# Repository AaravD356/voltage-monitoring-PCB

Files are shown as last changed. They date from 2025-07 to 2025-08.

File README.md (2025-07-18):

### UMD Mars Rover Electrical Team

### Voltage Monitoring PCB
This project involves a custom PCB designed to monitor the voltage of a multi-cell battery pack and transmit the readings over a CAN bus. The core of the system is an STM32 microcontroller, which reads the voltage of each cell through voltage divider circuits. The measured values are then transmitted via a SN65HVD230 CAN transceiver to a Jetson Nano, which acts as the receiver and processor.

### System Overview
The PCB includes six voltage divider circuits, one for each battery cell, to scale down the cell voltages to a level readable by the STM32's ADC inputs. The STM32 continuously reads these voltages and formats the data into a CAN message. The SN65HVD230 transceiver handles communication over the CAN bus, ensuring reliable data transfer to the Jetson Nano or any compatible receiver.

### CAN Communication
Each CAN message contains the measured voltages, formatted as an array of 16-bit unsigned integers representing millivolts. A static CAN ID is used to identify messages from the monitoring board. This ID can be customized in the STM32 firmware if needed.

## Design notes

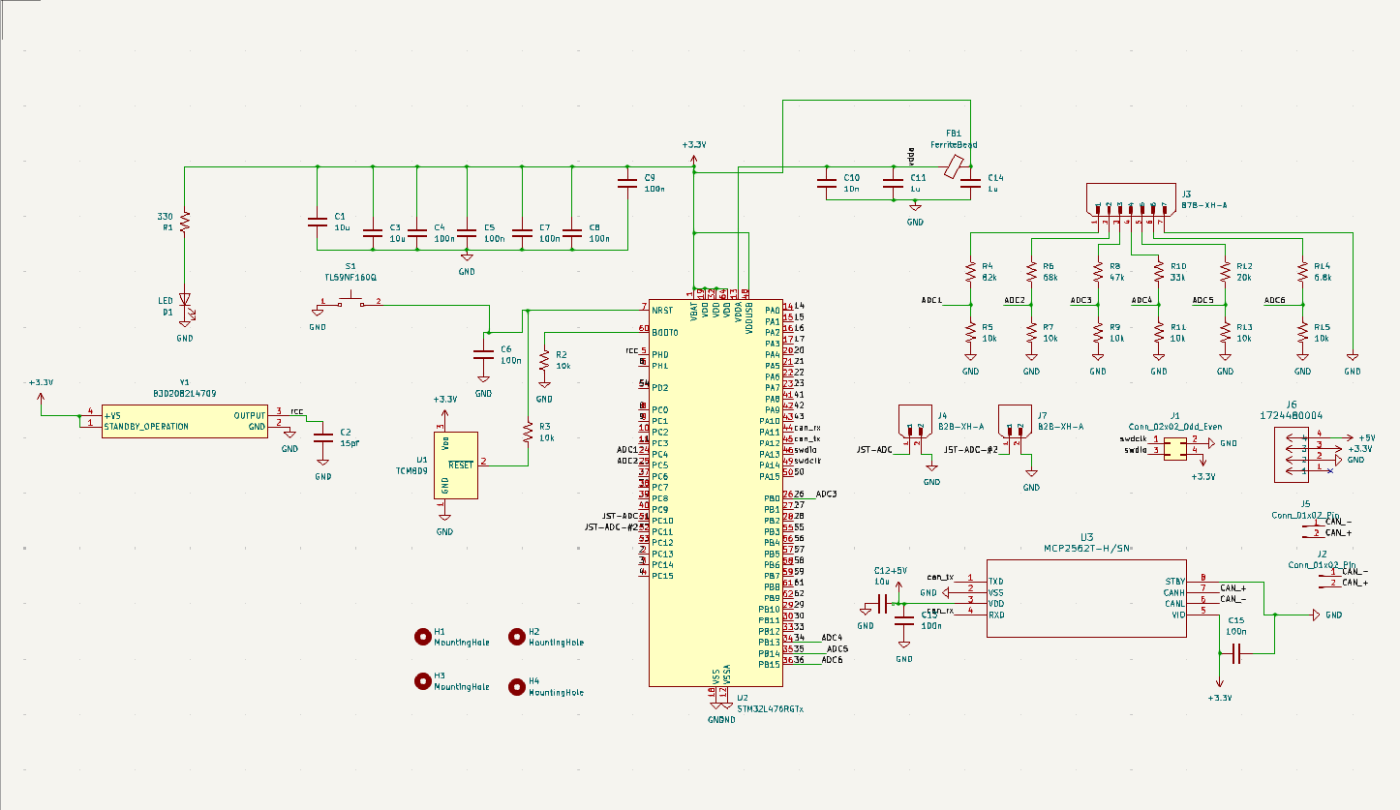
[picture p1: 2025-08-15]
Schematic.png

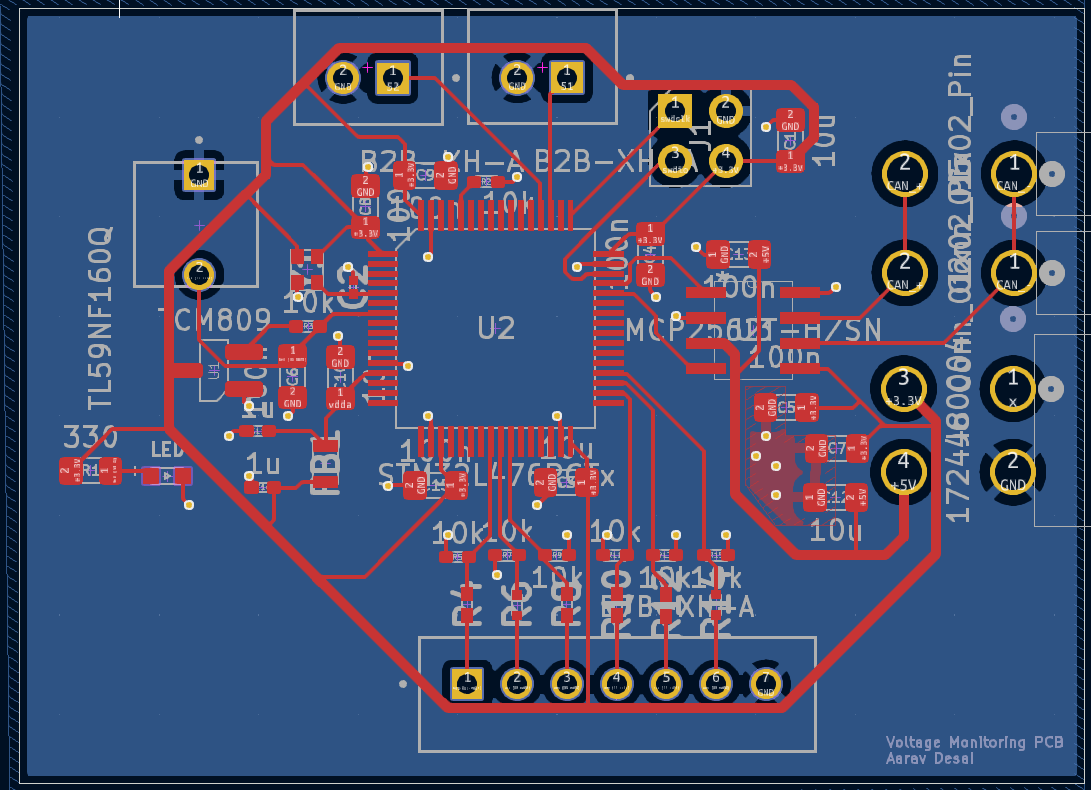
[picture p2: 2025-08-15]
Layout.png

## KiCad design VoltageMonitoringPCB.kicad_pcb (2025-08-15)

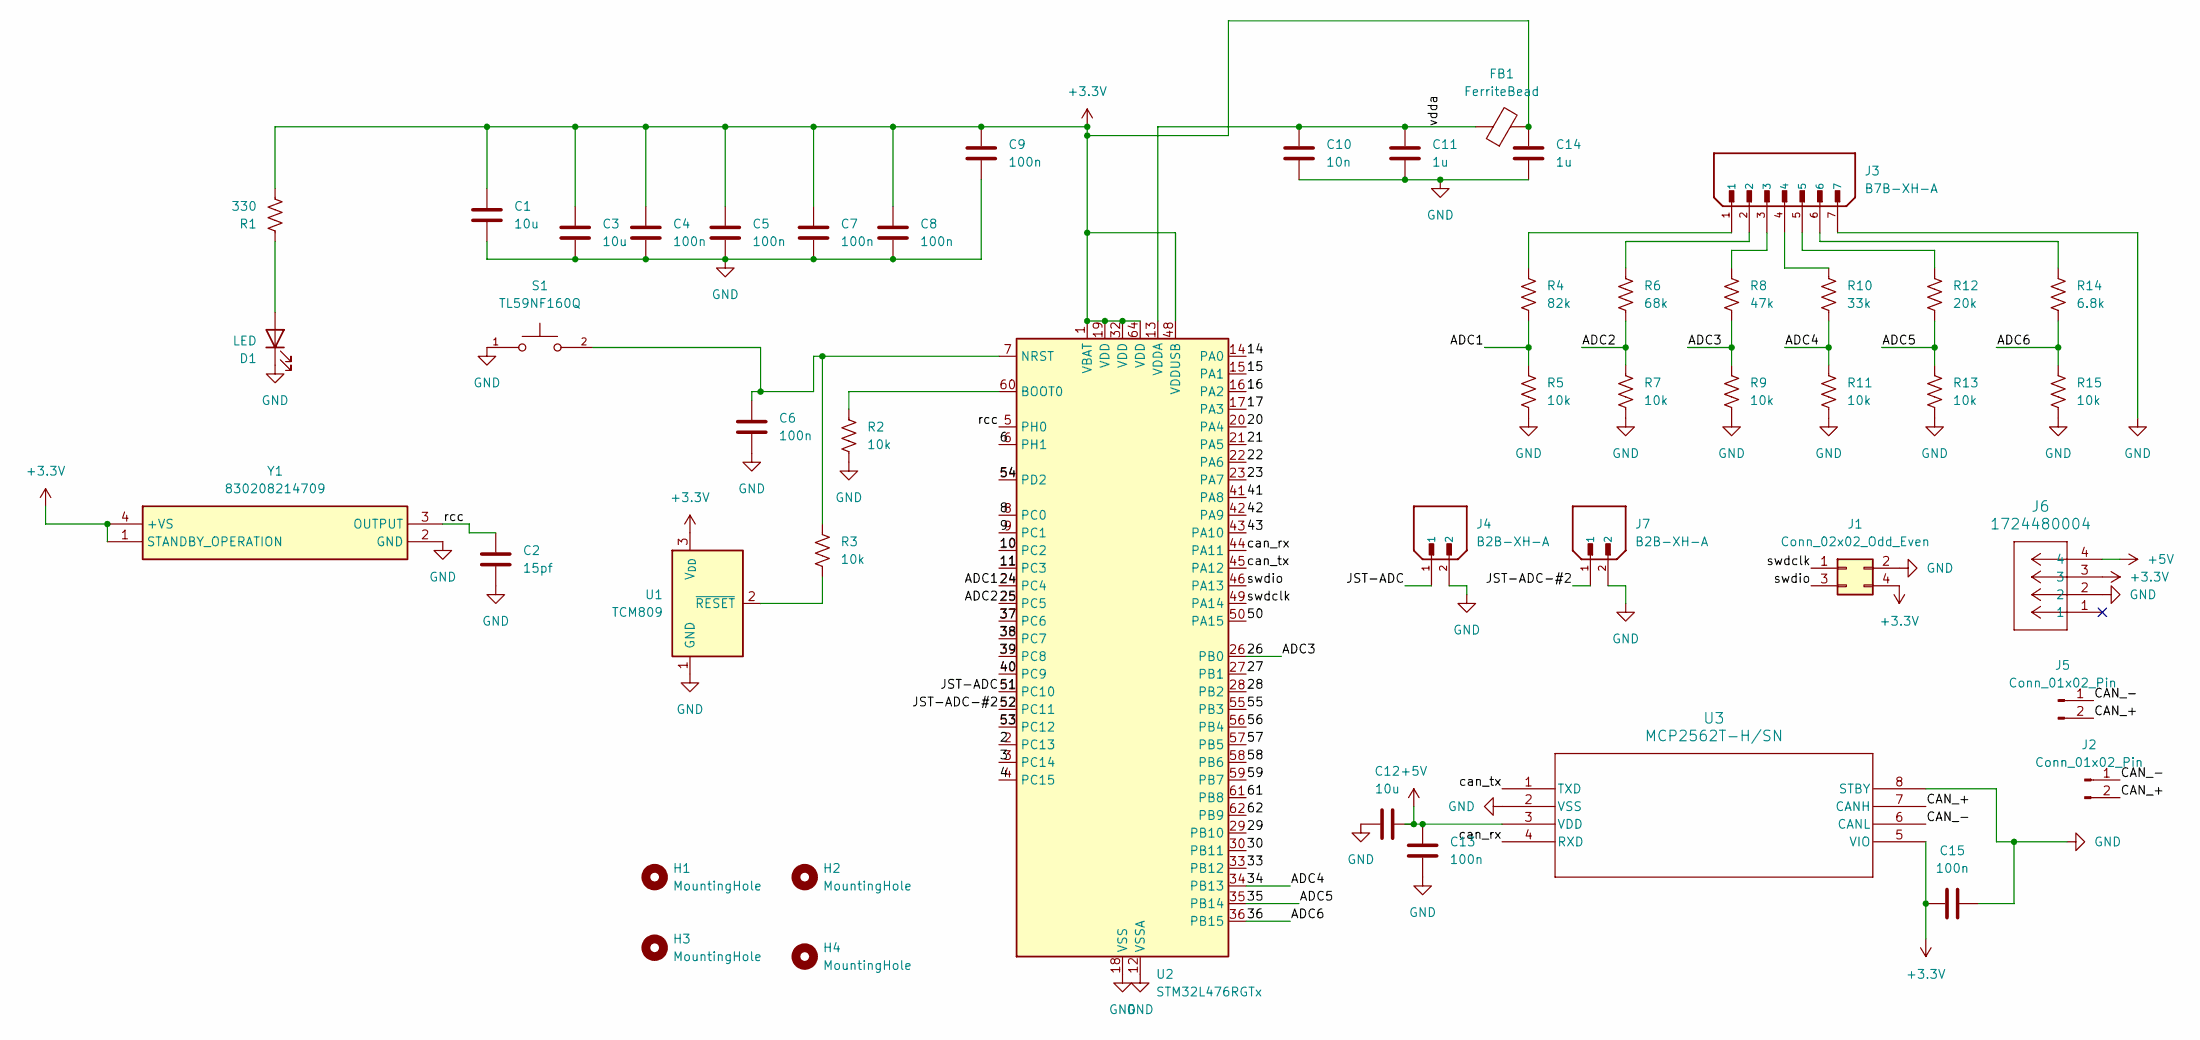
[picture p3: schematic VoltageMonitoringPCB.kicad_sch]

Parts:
C1, C3, C12: 10u; C_0805_2012Metric_Pad1.18x1.45mm_HandSolder
C2: 15pf; 15pf_cap
C4, C5, C6, C7, C8, C9, C13, C15: 100n; C_0805_2012Metric_Pad1.18x1.45mm_HandSolder
C10: 10n; C_0805_2012Metric_Pad1.18x1.45mm_HandSolder
C11, C14: 1u; C_0402_1005Metric_Pad0.74x0.62mm_HandSolder
D1: LED; small_led
FB1: FerriteBead; ferrite_bead02BH1J
H1, H2, H3, H4: MountingHole
J1: Conn_02x02_Odd_Even; PinHeader_2x02_P2.54mm_Vertical
J2, J5: Conn_01x02_Pin; can_molex_header
J3: B7B-XH-A; 7-PinJST-ad; PARTREV 7/4/21
J4, J7: B2B-XH-A; 2-PinJST-ad; PARTREV N/A
J6: 1724480004; power_header
R1: 330; R_0805_2012Metric_Pad1.20x1.40mm_HandSolder
R2, R3, R5, R7, R9, R11, R13, R15: 10k; R_0402_1005Metric_Pad0.72x0.64mm_HandSolder
R4: 82k; 82kOhmRes-ad
R6: 68k; 68kOhmRes-ad
R8: 47k; 47kOhmRes-ad
R10: 33k; 33kOhmRes-ad
R12: 20k; 20kOhmRes-ad
R14: 6.8k; 6.8kOhmRes-ad
S1: TL59NF160Q; reset_button; PARTREV G
U1: TCM809; SOT-23_Handsoldering
U2: STM32L476RGTx; LQFP-64_10x10mm_P0.5mm
U3: MCP2562T-H/SN; can_transceiver
Y1: 830208214709; oscillator; Mouser Part Number 710-830208214709

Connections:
+3.3V: C1.1, C3.1, C4.1, C5.1, C7.1, C8.1, C9.1, C14.1, C15.1, FB1.2, J1.4, J6.3, R1.2, U1.3 (V_{DD}), U2.1 (VBAT), U2.19 (VDD), U2.32 (VDD), U2.48 (VDDUSB), U2.64 (VDD), U3.5 (VIO), Y1.1 (STANDBY_OPERATION), Y1.4 (+VS)
+5V: C12.2, C13.2, J6.4, U3.3 (VDD)
/2: U2.2 (PC13)
/3: U2.3 (PC14)
/4: U2.4 (PC15)
/6: U2.6 (PH1)
/8: U2.8 (PC0)
/9: U2.9 (PC1)
/10: U2.10 (PC2)
/11: U2.11 (PC3)
/14: U2.14 (PA0)
/15: U2.15 (PA1)
/16: U2.16 (PA2)
/17: U2.17 (PA3)
/20: U2.20 (PA4)
/21: U2.21 (PA5)
/22: U2.22 (PA6)
/23: U2.23 (PA7)
/24: R4.2, R5.1, U2.24 (PC4)
/25: R6.2, R7.1, U2.25 (PC5)
/26: R8.2, R9.1, U2.26 (PB0)
/27: U2.27 (PB1)
/28: U2.28 (PB2)
/29: U2.29 (PB10)
/30: U2.30 (PB11)
/33: U2.33 (PB12)
/34: R10.2, R11.1, U2.34 (PB13)
/35: R12.2, R13.1, U2.35 (PB14)
/36: R14.2, R15.1, U2.36 (PB15)
/37: U2.37 (PC6)
/38: U2.38 (PC7)
/39: U2.39 (PC8)
/40: U2.40 (PC9)
/41: U2.41 (PA8)
/42: U2.42 (PA9)
/43: U2.43 (PA10)
/50: U2.50 (PA15)
/51: J4.1, U2.51 (PC10)
/52: J7.1, U2.52 (PC11)
/53: U2.53 (PC12)
/54: U2.54 (PD2)
/55: U2.55 (PB3)
/56: U2.56 (PB4)
/57: U2.57 (PB5)
/58: U2.58 (PB6)
/59: U2.59 (PB7)
/61: U2.61 (PB8)
/62: U2.62 (PB9)
/CAN_+: J2.2, J5.2, U3.7 (CANH)
/CAN_-: J2.1, J5.1, U3.6 (CANL)
/can_rx: U2.44 (PA11), U3.4 (RXD)
/can_tx: U2.45 (PA12), U3.1 (TXD)
/rcc: C2.1, U2.5 (PH0), Y1.3 (OUTPUT)
/swdclk: J1.1, U2.49 (PA14)
/swdio: J1.3, U2.46 (PA13)
/vdda: C10.1, C11.1, FB1.1, U2.13 (VDDA)
GND: C1.2, C2.2, C3.2, C4.2, C5.2, C6.2, C7.2, C8.2, C9.2, C10.2, C11.2, C12.1, C13.1, C14.2, C15.2, D1.1 (K), J1.2, J3.7, J4.2, J6.2, J7.2, R2.2, R5.2, R7.2, R9.2, R11.2, R13.2, R15.2, S1.1, U1.1 (GND), U2.12 (VSSA), U2.18 (VSS), U2.31 (VSS), U2.47 (VSS), U2.63 (VSS), U3.2 (VSS), U3.8 (STBY), Y1.2 (GND)
unnamed: D1.2 (A), R1.1
unnamed: J3.1, R4.1
unnamed: J3.2, R6.1
unnamed: J3.3, R8.1
unnamed: J3.4, R10.1
unnamed: J3.5, R12.1
unnamed: J3.6, R14.1
unnamed: R3.2, U1.2 (~RESET)
unnamed: R2.1, U2.60 (BOOT0)
unnamed: C6.1, R3.1, S1.2, U2.7 (NRST)

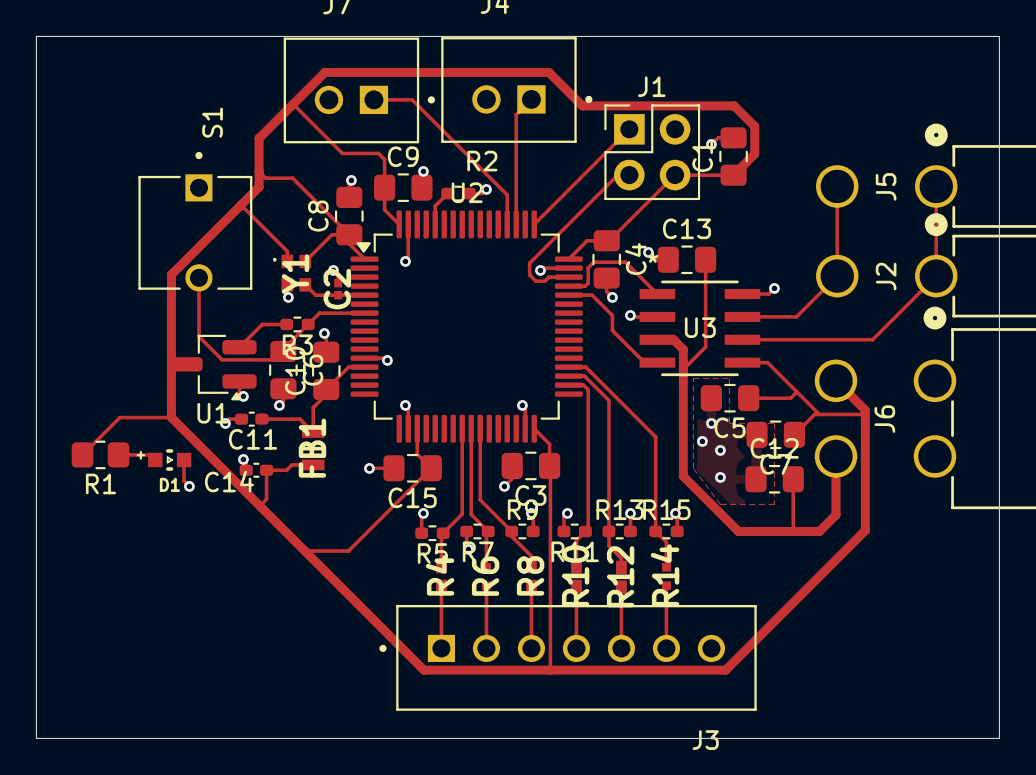
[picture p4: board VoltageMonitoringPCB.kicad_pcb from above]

Board: 2 copper layers, 53.5 x 39.0 mm, 44 parts (0 on the bottom side), 29 nets.

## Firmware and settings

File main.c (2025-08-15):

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

#include "main.h"
#include <string.h>
#include <stdbool.h>

/* =================== CONFIG =================== */
// Firmware version
#define FW_MAJOR        1
#define FW_MINOR        0
#define FW_PATCH        0
#define FW_VERSION_U32  ((FW_MAJOR<<24)|(FW_MINOR<<16)|(FW_PATCH))

// ADC config
#define NUM_ADC_CH      6
#define ADC_SAMPLES     16
#define VREF_MV         3300
#define ADC_FS_COUNTS   4095.0f

// ADC scan order indices
enum {
  CH_ADC1 = 0, // PC4
  CH_ADC2,     // PC5
  CH_ADC3,     // PB0
  CH_ADC4,     // PB13
  CH_ADC5,     // PB14
  CH_ADC6      // PB15
};

// Divider gains (Rtop+Rbot)/Rbot
static const float k_divider_gain[NUM_ADC_CH] = {
  9.2f,   // ADC1: 82k/10k
  7.8f,   // ADC2: 68k/10k
  5.7f,   // ADC3: 47k/10k
  4.3f,   // ADC4: 33k/10k
  3.0f,   // ADC5: 20k/10k
  1.68f   // ADC6: 6.8k/10k
};

// Fault thresholds
#define UV_TRIP_MV        3000
#define UV_WARN_MV        3200
#define OV_WARN_MV        4200
#define OV_TRIP_MV        4250
#define IMBALANCE_WARN_MV 100
#define FAULT_DEBOUNCE_MS 500

// MCP2562 STBY pin
#define CAN_STBY_GPIO_Port     GPIOB
#define CAN_STBY_Pin           GPIO_PIN_2

// Relay JSTs (initialized, unused)
#define RELAY1_GPIO_Port       GPIOC
#define RELAY1_Pin             GPIO_PIN_10
#define RELAY2_GPIO_Port       GPIOC
#define RELAY2_Pin             GPIO_PIN_11

// CAN IDs
#define CAN_ID_HEARTBEAT   0x300
#define CAN_ID_VOLTAGES_1  0x301
#define CAN_ID_VOLTAGES_2  0x302
#define CAN_ID_FAULTS      0x303

/* =================== PRIVATE VARS =================== */
ADC_HandleTypeDef hadc1;
DMA_HandleTypeDef hdma_adc1;
CAN_HandleTypeDef hcan;
TIM_HandleTypeDef htim2;

static volatile uint16_t adc_dma_buf[NUM_ADC_CH * ADC_SAMPLES];
static volatile uint16_t meas_mV[NUM_ADC_CH];

static volatile uint32_t uptime_ms = 0;
static uint32_t last_hb_ms = 0;
static uint32_t last_tx_ms = 0;
static uint32_t status_bits = 0;

/* =================== PROTOTYPES =================== */
void SystemClock_Config(void);
static void MX_GPIO_Init(void);
static void MX_DMA_Init(void);
static void MX_ADC1_Init(void);
static void MX_CAN_Init(void);
static void MX_TIM2_Init(void);

static void start_adc_dma(void);
static void process_adc_window(void);
static void evaluate_faults(void);
static void can_send_std(uint16_t id, const uint8_t *data, uint8_t len);
static void tx_heartbeat(void);
static void tx_voltages(void);
static void tx_faults(void);

/* =================== MAIN =================== */
int main(void)
{
  HAL_Init();
  SystemClock_Config();

  MX_GPIO_Init();
  MX_DMA_Init();
  MX_ADC1_Init();
  MX_CAN_Init();
  MX_TIM2_Init();

  // Enable CAN transceiver
  HAL_GPIO_WritePin(CAN_STBY_GPIO_Port, CAN_STBY_Pin, GPIO_PIN_RESET);

  HAL_CAN_Start(&hcan);
  HAL_CAN_ActivateNotification(&hcan, CAN_IT_TX_MAILBOX_EMPTY);
  HAL_TIM_Base_Start_IT(&htim2);

  start_adc_dma();

  while (1)
  {
    uint32_t now = uptime_ms;

    if (now - last_hb_ms >= 500) {
      tx_heartbeat();
      last_hb_ms = now;
    }
    if (now - last_tx_ms >= 100) {
      tx_voltages();
      tx_faults();
      last_tx_ms = now;
    }
    HAL_Delay(5);
  }
}

/* =================== CALLBACKS =================== */
void HAL_TIM_PeriodElapsedCallback(TIM_HandleTypeDef *htim)
{
  if (htim == &htim2) uptime_ms++;
}

void HAL_ADC_ConvCpltCallback(ADC_HandleTypeDef *hadc)
{
  if (hadc == &hadc1) {
    process_adc_window();
    evaluate_faults();
  }
}

/* =================== FUNCTIONS =================== */
static void start_adc_dma(void)
{
  HAL_ADC_Start_DMA(&hadc1, (uint32_t*)adc_dma_buf, NUM_ADC_CH * ADC_SAMPLES);
}

static void process_adc_window(void)
{
  for (int ch = 0; ch < NUM_ADC_CH; ch++) {
    uint32_t acc = 0;
    for (int s = 0; s < ADC_SAMPLES; s++)
      acc += adc_dma_buf[ch + s*NUM_ADC_CH];
    float avg_counts = (float)acc / ADC_SAMPLES;
    float mv_adc = (avg_counts * VREF_MV) / ADC_FS_COUNTS;
    float mv_node = mv_adc * k_divider_gain[ch];
    if (mv_node < 0) mv_node = 0;
    if (mv_node > 65535) mv_node = 65535;
    meas_mV[ch] = (uint16_t)mv_node;
  }
}

static void evaluate_faults(void)
{
  uint32_t faults = 0;
  uint16_t vmin = 0xFFFF, vmax = 0;

  for (int ch = 0; ch < NUM_ADC_CH; ch++) {
    uint16_t v = meas_mV[ch];
    if (v <= UV_TRIP_MV) faults |= (1u << ch);
    if (v >= OV_TRIP_MV) faults |= (1u << (8 + ch));
    vmin = (v < vmin) ? v : vmin;
    vmax = (v > vmax) ? v : vmax;
  }
  if ((uint16_t)(vmax - vmin) >= IMBALANCE_WARN_MV)
    faults |= (1u << 16);

  static uint32_t first_fault_ms = 0;
  if (faults) {
    if (!first_fault_ms) first_fault_ms = uptime_ms;
    if (uptime_ms - first_fault_ms >= FAULT_DEBOUNCE_MS)
      status_bits = faults;
  } else {
    first_fault_ms = 0;
    status_bits = 0;
  }
}

static void can_send_std(uint16_t id, const uint8_t *data, uint8_t len)
{
  CAN_TxHeaderTypeDef tx = {0};
  uint32_t mbox;
  tx.StdId = id;
  tx.IDE   = CAN_ID_STD;
  tx.RTR   = CAN_RTR_DATA;
  tx.DLC   = len & 0x0F;
  HAL_CAN_AddTxMessage(&hcan, &tx, (uint8_t*)data, &mbox);
}

static void tx_heartbeat(void)
{
  uint8_t p[8] = {0};
  uint32_t up100ms = uptime_ms / 100;
  p[0]= (uint8_t)(up100ms);
  p[1]= (uint8_t)(up100ms>>8);
  p[2]= (uint8_t)(up100ms>>16);
  p[3]= (uint8_t)(up100ms>>24);
  p[4]= (uint8_t)(FW_VERSION_U32>>24);
  p[5]= (uint8_t)(FW_VERSION_U32>>16);
  p[6]= (uint8_t)(FW_VERSION_U32>>8);
  p[7]= (uint8_t)(FW_VERSION_U32);
  can_send_std(CAN_ID_HEARTBEAT, p, 8);
}

static void tx_voltages(void)
{
  uint8_t p1[8] = {
    (uint8_t)(meas_mV[CH_ADC1]>>8), (uint8_t)(meas_mV[CH_ADC1]),
    (uint8_t)(meas_mV[CH_ADC2]>>8), (uint8_t)(meas_mV[CH_ADC2]),
    (uint8_t)(meas_mV[CH_ADC3]>>8), (uint8_t)(meas_mV[CH_ADC3]),
    (uint8_t)(meas_mV[CH_ADC4]>>8), (uint8_t)(meas_mV[CH_ADC4])
  };
  can_send_std(CAN_ID_VOLTAGES_1, p1, 8);

  uint8_t p2[8] = {
    (uint8_t)(meas_mV[CH_ADC5]>>8), (uint8_t)(meas_mV[CH_ADC5]),
    (uint8_t)(meas_mV[CH_ADC6]>>8), (uint8_t)(meas_mV[CH_ADC6]),
    0,0,0,0
  };
  can_send_std(CAN_ID_VOLTAGES_2, p2, 8);
}

static void tx_faults(void)
{
  uint8_t p[8] = {0};
  uint32_t sb = status_bits;
  p[0]=(uint8_t)(sb);
  p[1]=(uint8_t)(sb>>8);
  p[2]=(uint8_t)(sb>>16);
  p[3]=(uint8_t)(sb>>24);
  can_send_std(CAN_ID_FAULTS, p, 8);
}

/* =================== CubeMX Init Stubs =================== */
/* Configure ADC ranks in CubeMX:
   Rank1: PC4  (ADC1_IN14)
   Rank2: PC5  (ADC1_IN15)
   Rank3: PB0  (ADC1_IN8)
   Rank4: PB13 (ADC1_IN5)
   Rank5: PB14 (ADC1_IN6)
   Rank6: PB15 (ADC1_IN7)
   DMA: Circular, half-word
*/
/* =================== CubeMX Init Stubs / Minimal implementations =================== */

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
